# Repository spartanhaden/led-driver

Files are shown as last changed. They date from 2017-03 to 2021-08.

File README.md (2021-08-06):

# LED driver

This repo contains code for a [Particle Photon](https://docs.particle.io/quickstart/photon/) used to control a strip of 12V RGB LEDs connected to a custom designed a PCB. The brd and sch files are also included.



## Schematic
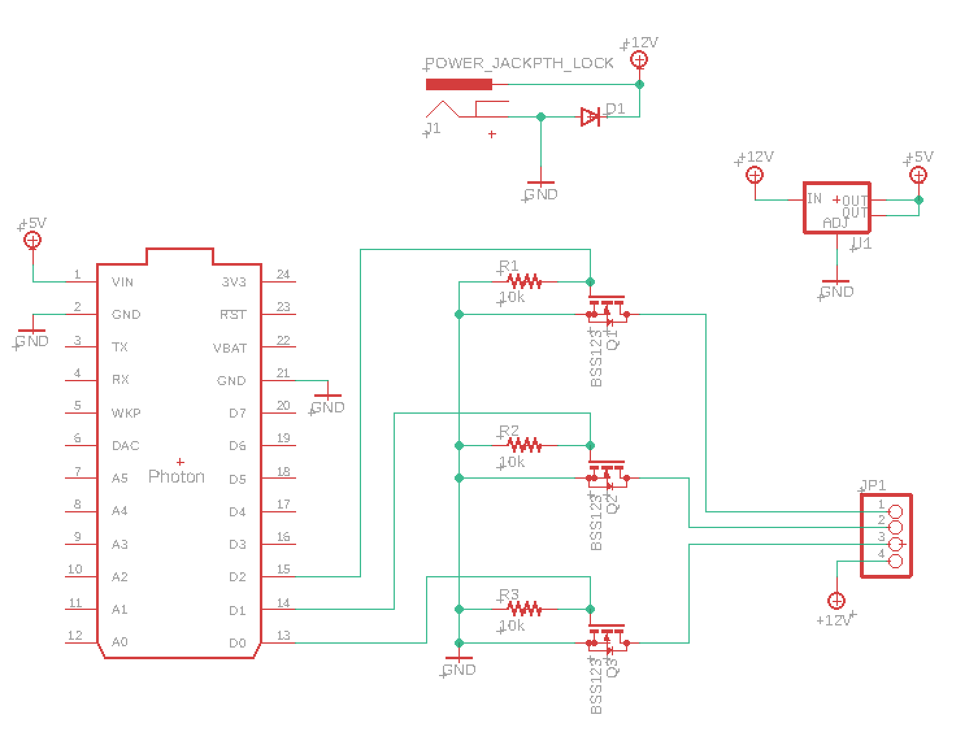
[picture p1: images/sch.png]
schematic

## Board
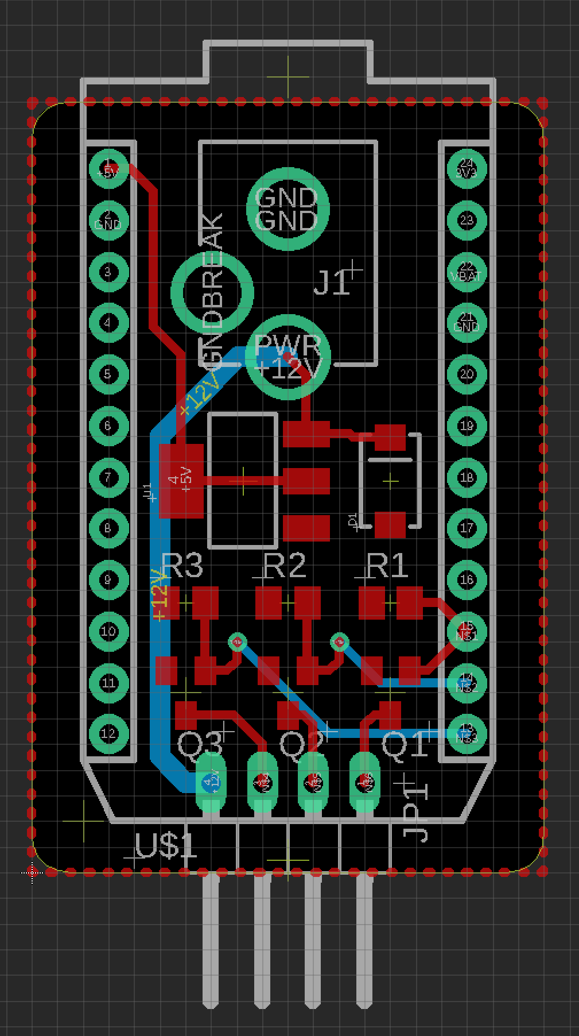
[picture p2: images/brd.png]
board

## Breadboard
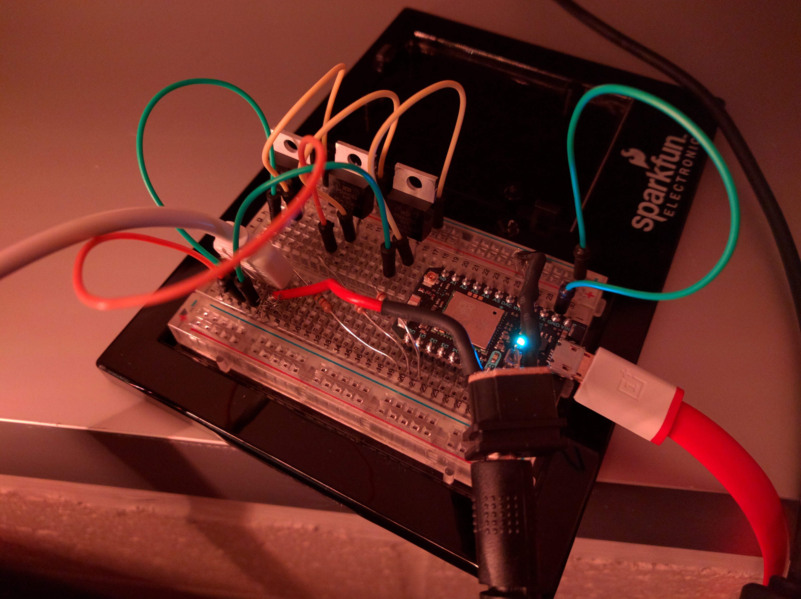
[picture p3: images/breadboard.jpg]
breadboard

## PCB
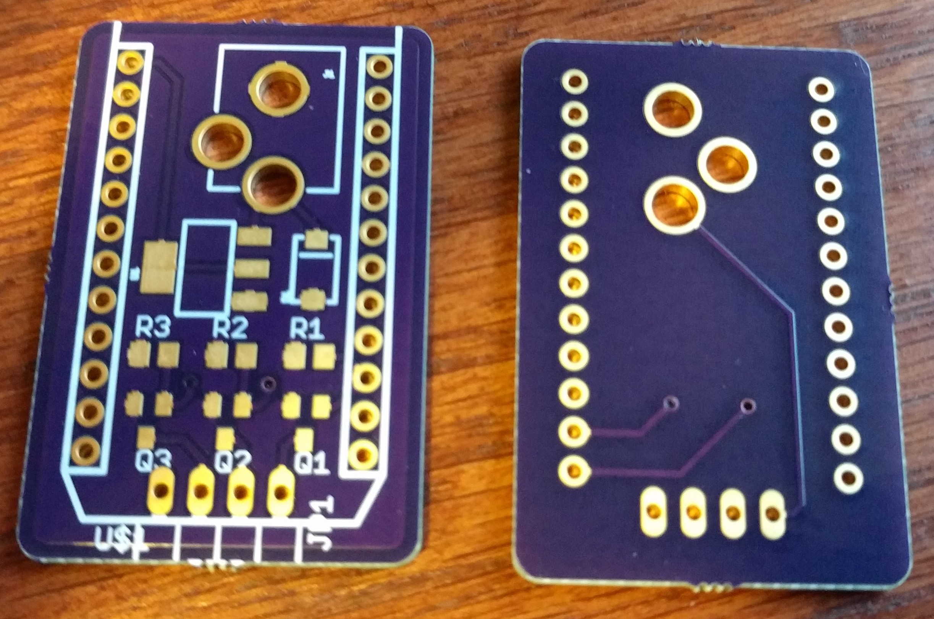
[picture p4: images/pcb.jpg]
pcb

## Assembled PCB
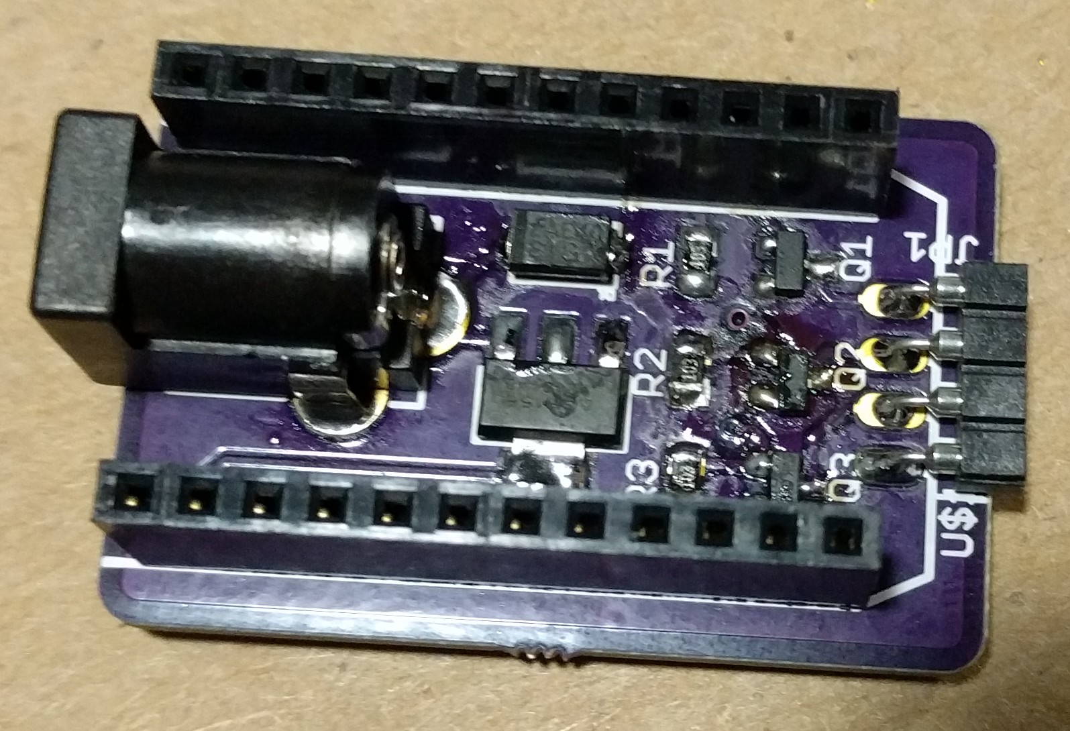
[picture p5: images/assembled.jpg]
assembled

## Assembled unit
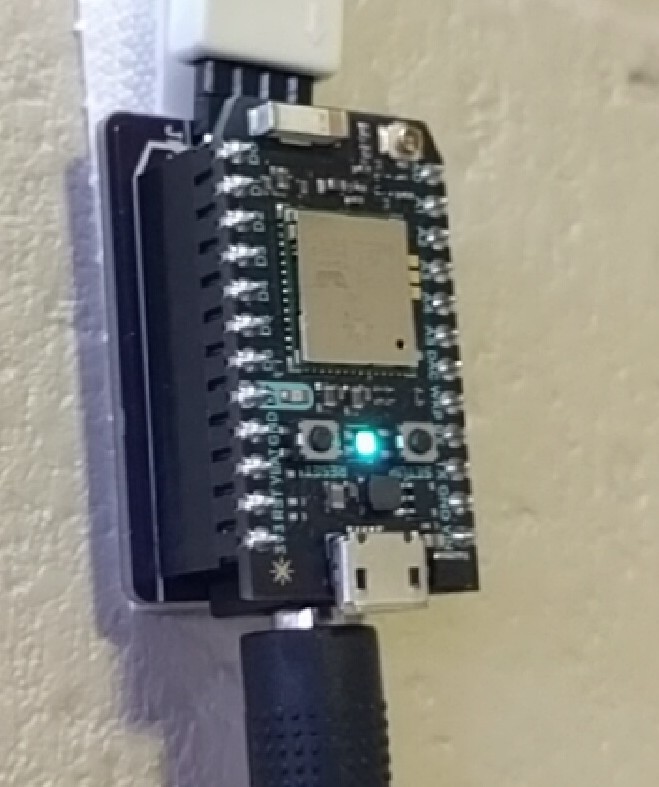
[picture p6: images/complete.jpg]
complete


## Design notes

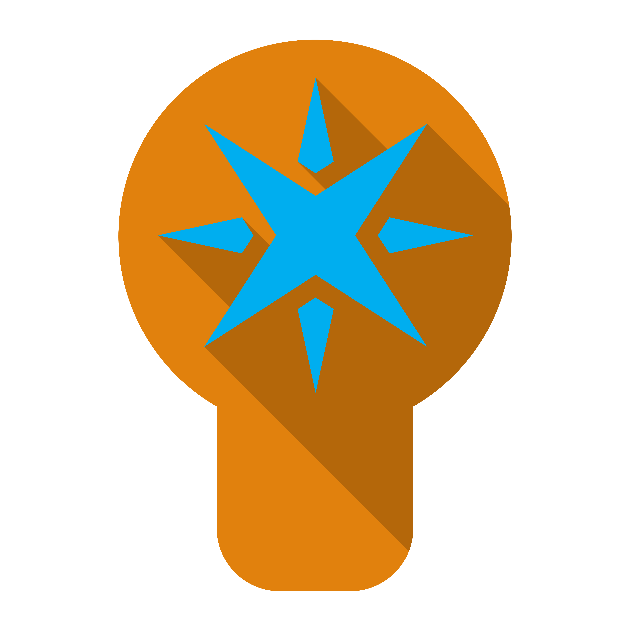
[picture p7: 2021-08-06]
logo/lights.png

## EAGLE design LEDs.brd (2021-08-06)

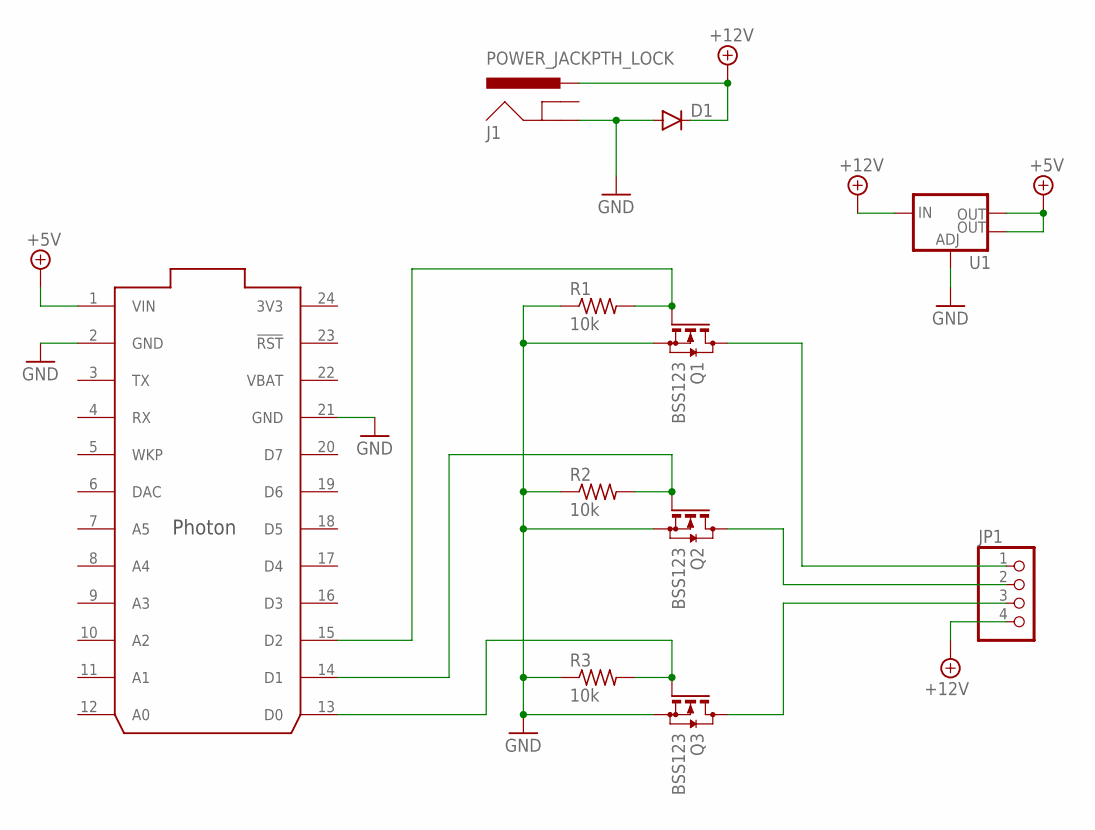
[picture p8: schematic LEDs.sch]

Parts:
D1: DIODESMA; SMA-DIODE
J1: POWER_JACKPTH_LOCK; POWER_JACK_PTH_LOCK
JP1: PINHD-1X4/90; 1X04/90
Q1, Q2, Q3: BSS123; SOT23
R1, R2, R3: 10k; M0805
U1: V_REG_LM1117SOT223; SOT223
U$1: PHOTON_WITH_HEADERS; PHOTON

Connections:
3V3: U$1.24 (3V3)
+5V: U1.2 (OUT), U1.4 (OUT), U$1.1 (VIN)
+12V: D1.C, J1.PWR, JP1.4, U1.3 (IN)
GND: D1.A, J1.GND, Q1.2 (S), Q2.2 (S), Q3.2 (S), R1.1, R2.1, R3.1, U1.1 (ADJ), U$1.2 (GND), U$1.21 (GND)
unnamed: Q1.1 (G), R1.2, U$1.15 (D2)
unnamed: Q2.1 (G), R2.2, U$1.14 (D1)
unnamed: Q3.1 (G), R3.2, U$1.13 (D0)
unnamed: JP1.3, Q3.3 (D)
unnamed: JP1.2, Q2.3 (D)
unnamed: JP1.1, Q1.3 (D)
VBAT: U$1.22 (VBAT)

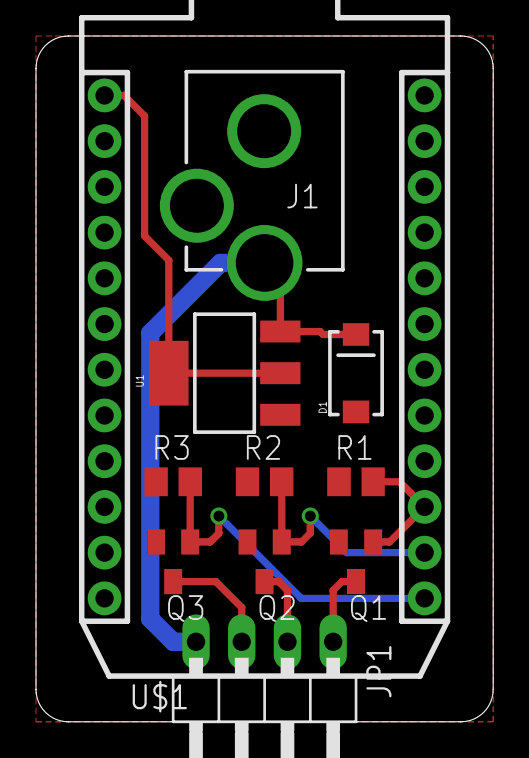
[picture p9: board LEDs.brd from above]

Board: 2 copper layers, 25.4 x 38.1 mm, 11 parts (0 on the bottom side), 9 nets.

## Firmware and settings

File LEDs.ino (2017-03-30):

#define GREEN   D2
#define RED     D1
#define BLUE    D0
#define REFRESH_RATE 1000

// Gamma corrected LED values
const uint32_t gamma_vals[] = {
    0,  0,  0,  0,  0,  0,  0,  0,  0,  0,  0,  0,  0,  0,  0,  0,
    0,  0,  0,  0,  0,  0,  0,  0,  0,  0,  0,  0,  1,  1,  1,  1,
    1,  1,  1,  1,  1,  1,  1,  1,  1,  2,  2,  2,  2,  2,  2,  2,
    2,  3,  3,  3,  3,  3,  3,  3,  4,  4,  4,  4,  4,  5,  5,  5,
    5,  6,  6,  6,  6,  7,  7,  7,  7,  8,  8,  8,  9,  9,  9, 10,
   10, 10, 11, 11, 11, 12, 12, 13, 13, 13, 14, 14, 15, 15, 16, 16,
   17, 17, 18, 18, 19, 19, 20, 20, 21, 21, 22, 22, 23, 24, 24, 25,
   25, 26, 27, 27, 28, 29, 29, 30, 31, 32, 32, 33, 34, 35, 35, 36,
   37, 38, 39, 39, 40, 41, 42, 43, 44, 45, 46, 47, 48, 49, 50, 50,
   51, 52, 54, 55, 56, 57, 58, 59, 60, 61, 62, 63, 64, 66, 67, 68,
   69, 70, 72, 73, 74, 75, 77, 78, 79, 81, 82, 83, 85, 86, 87, 89,
   90, 92, 93, 95, 96, 98, 99,101,102,104,105,107,109,110,112,114,
  115,117,119,120,122,124,126,127,129,131,133,135,137,138,140,142,
  144,146,148,150,152,154,156,158,160,162,164,167,169,171,173,175,
  177,180,182,184,186,189,191,193,196,198,200,203,205,208,210,213,
  215,218,220,223,225,228,231,233,236,239,241,244,247,249,252,255 };

double brightness = 0.0;
double target = 1.0;

// Values I use at night for a soft light
const uint8_t red = 255, green = 170, blue = 90;

// Causes device to turn on lights before connecting to Wi-Fi
SYSTEM_MODE(SEMI_AUTOMATIC);

void setup() {
	// Set the correct pins to outputs
	pinMode(RED, OUTPUT);
	pinMode(GREEN, OUTPUT);
	pinMode(BLUE, OUTPUT);

	// Initial turn on of lights.
	while (brightness <= 1.00) {
		brightness += 0.01;
		setColor(red * brightness, green * brightness, blue * brightness);
		delay(10);
	}

	// Connect the particle to Wi-Fi and setup remote control
	Particle.connect();
	Particle.function("switch", switchState);
}

void loop() {
	Particle.process();
	checkLEDs();
}

// Handles checking of the LED state
void checkLEDs() {
	if (brightness < target - 0.005) {
		brightness += 0.01;
		setColor(red * brightness, green * brightness, blue * brightness);
		RGB.brightness(int(brightness * 254) + 1);
		delay(10);
	} else if (brightness > target + 0.005) {
		brightness -= 0.01;
		setColor(red * brightness, green * brightness, blue * brightness);
		RGB.brightness(int(brightness * 254) + 1);
		delay(10);
	}
}

// Takes input to set the lights
int switchState(String command) {
	int input = atoi(command);

	// Toggles the lights if input is -1
	if (input == -1) {
		if (target < 0.3)
			target = 1.0;
		else
			target = 0.0;
		return 1;
	}

	// Constrain the input value between 0 and 100
	if (input < 0)
		input = 0;
	else if (input > 100)
		input = 100;

	// Convert to 0.0 to 1.0
	target = atof(command) / 100.0;

	return 1;
}

// Sets the color of the lights to the gamma corrected value for the given colors
void setColor(uint8_t red, uint8_t green, uint8_t blue) {
	analogWrite(RED, gamma_vals[red], REFRESH_RATE);
	analogWrite(GREEN, gamma_vals[green], REFRESH_RATE);
	analogWrite(BLUE, gamma_vals[blue], REFRESH_RATE);
}

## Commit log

2016-03-01 Created color function, added gamma correction, and switched pins
    [LEDs.ino]
2016-03-23 Fixes, Polling, and functions.
    Moved LEDs to separate function, fixed naming bug, added checking of
    cloud connection for messages.
    [LEDs.ino]
2016-03-23 Return final state of LEDs
2016-03-24 Changed threshold, and dimmed onboard LED when disabled.
2016-04-05 Switched to state based system
    State 2 is only available between 1 AM and 7 AM. It is a dimmed mode
    for pleasant reading before bedtime.
2021-08-06 Fixes incorrect voltage
2021-08-06 Adds PCB files
    [LEDs.brd, LEDs.sch]

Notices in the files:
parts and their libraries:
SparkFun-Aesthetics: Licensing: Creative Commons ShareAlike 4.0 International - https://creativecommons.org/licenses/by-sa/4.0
